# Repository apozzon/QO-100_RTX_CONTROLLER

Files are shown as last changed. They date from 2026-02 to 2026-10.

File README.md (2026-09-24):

# QO-100_RTX_CONTROLLER
QO-100 RTX CONTROLLER
ESP32 CONTROLLER for QO100
 	 	 	 	 	 	 	 	 	 	 	 	 	 	 	 	 
 	QO-100 RTX		IP		SSID		PASSW	 
 	Controller		192.168.0.214		SKYAP2		************	 
 																 
 	ON/OFF		DATV		GPSDO		FAN		…		…		…		…	 

 	V in		V pow		A pow		mW in		W out		W ref		SWR		T air-pow	 
 	13.8		27.5		1.5		10		7,5		0,6		1,788789		19-33	 

DRAFT COPY - SOON IN ENGLISH

Misure
Parametro	Max	PIN	Note
V ingresso	13.8 V	1	Partitore 1:10
V potenza	30V	2	Partitore 1:10
A potenza	10A	3	Parallelo a R 0,1 ohm da 5 W (10A = 1V)
W power in 	5V	4	
W power out	5V	5	
W reflected	5V	6	
C temperatura	60C	11	Apposito modulo digitale

Controlli
Parametro	Stato	PIN	Note
On / Off	0-1	7	Accende e spegne SDR – Arduino sempre on low
DATV	0-1	8	Commuta 12V-18V su Bias-T
Heat	0-1	9	Accende resistenza riscaldamento clima freddo

INSTALLAZIONE IDE E SETTAGGIO BOARD
Setup Steps for Arduino IDE
1.	Open Arduino IDE and go to File > Preferences.
2.	Add Board Manager URL: Paste the following into the "Additional Boards Manager URLs" field:
https://raw.githubusercontent.com/espressif/arduino-esp32/gh-pages/package_esp32_index.json.
3.	Install Boards: Go to Tools > Board > Boards Manager, search for "esp32" and install the latest version by Espressif Systems.
 
NB: se non carica support mettere queste due istruzioni in C:\Users\Andrea.DESKTOP-IK5K4JJ\.arduinoIDE\ arduino-cli.yaml
network:
  connection_timeout: 300s

4.	Select Board: Select Tools > Board > ESP32 Arduino > ESP32S3 Dev Module.
5.	Configure Tools Menu (Crucial for N16R8):
1.	USB CDC On Boot: "Enabled" (Allows Serial.print via USB).
2.	Flash Size: "16MB (128Mb)".
3.	Flash Mode: "QIO 80MHz" or "QOIO 80MHz".
4.	Partition Scheme: "16M Flash (3M APP/9.9M FATFS)" or similar large partition.
5.	PSRAM: "OPI PSRAM".
6.	Upload: Connect the board, select the correct Port, and upload a test sketch. 

ARDUINO
Additional board manager URL: https://espressif.github.io/arduino-esp32/package_esp32_index.json
Board scelta : ESP32S3 Dev Module

Librerie
https://github.com/ESP32Async/AsyncTCP
https://github.com/ESP32Async/ESPAsyncWebServer
DHT kxn

Java aggiunta libreria Google json
tasto destro su Progetto – Build Path -Add External Archives) – Scegliere file scaricato (es.  gson-2.3.1.jar)

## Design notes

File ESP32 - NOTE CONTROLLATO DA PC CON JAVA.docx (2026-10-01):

# ESP32 CONTROLLER PER QO100

https://github.com/apozzon/QO-100_RTX_CONTROLLER

| QO-100 RTX | | | | IP | | | | SSID | | | | PASSW
| Controller | | | | 192.168.0.214 | | | | SKYAP2 | | | | ************
| ON/OFF | | DATV | | GPSDO | | … | | … | | … | | … | | …
| V in | | V pow | | A pow | | mW in | | W out | | W ref | | SWR | | T air-pow
| 13.8 | | 27.5 | | 1.5 | | 10 | | 7,5 | | 0,6 | | 1,78 | | 19-33

## Misure

Parametro | Max | PIN | Note
V ingresso | 13.8 V | 1 | Partitore 1:10
V potenza | 30V | 2 | Partitore 1:10
A potenza | 5A | 3 | ASC712-5A
W power in | 5V | 4
W power out | 5V | 5
W reflected | 5V | 6
C temperatura aria | 60C | 11 | DHT22
C P.A. | 60C | 10 | DB18S20

## Controlli

Parametro | Stato | PIN | Note
On / Off | 0-1 | 7 | Accende e spegne SDR – Arduino sempre on low
DATV | 0-1 | 8 | Commuta 12V-18V su Bias-T
GPSDO | 0-1 | 9 | Accende GPSDO

## ARDUINO - INSTALLAZIONE IDE E SETTAGGIO BOARD

Setup Steps for Arduino IDE

NB: se non carica support mettere queste due istruzioni in C:\Users\Andrea.DESKTOP-IK5K4JJ\.arduinoIDE\ arduino-cli.yaml

network:

connection_timeout: 300s

1. Open Arduino IDE and go to File > Preferences.
2. Add Board Manager URL: Paste the following into the "Additional Boards Manager URLs" field: https://raw.githubusercontent.com/espressif/arduino-esp32/gh-pages/package_esp32_index.json
3. https://github.com/ESP32Async/ESPAsyncWebServer
4. Install Boards: Go to Tools > Board > Boards Manager, search for "esp32" and install the latest version by Espressif Systems.

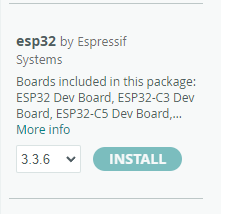
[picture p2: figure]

5. Select Board: Select Tools > Board > ESP32 Arduino > ESP32S3 Dev Module.
6. Configure Tools Menu (Crucial for N16R8):
  - USB CDC On Boot: "Enabled" (Allows Serial.print via USB).
  - Flash Size: "16MB (128Mb)".
  - Flash Mode: "QIO 80MHz" or "QOIO 80MHz".
  - Partition Scheme: "16M Flash (3M APP/9.9M FATFS)" or similar large partition.
  - PSRAM: "OPI PSRAM".
7. Upload: Connect the board, select the correct Port, and upload a test sketch.

## Installazione librerie

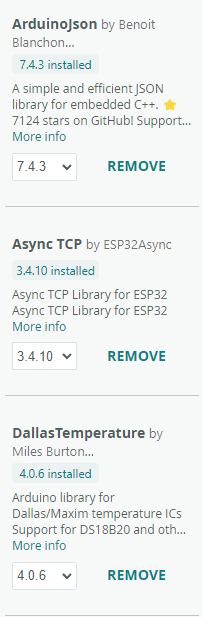
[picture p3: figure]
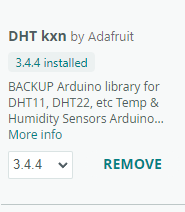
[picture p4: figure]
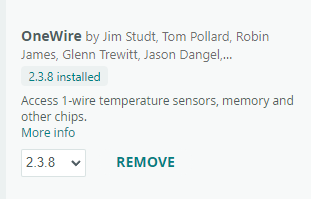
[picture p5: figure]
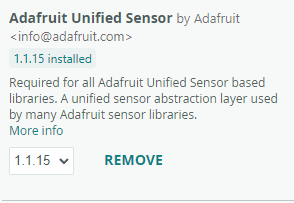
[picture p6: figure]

Vengono salvate nella directory di progetto

C:\Users\Andrea.DESKTOP-IK5K4JJ\OneDrive\RADIO\Autocostruzione\OSCAR-100\$ Programmazione\Arduino_ESP32\libraries

Si possono copiare nella nuova installazione chiudere e riaprire IDE che si caricano da sole.

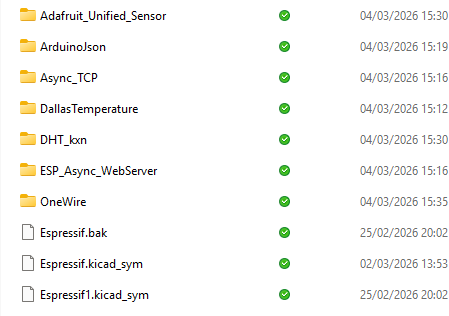
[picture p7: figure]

# JAVA aggiunta libreria Google json

tasto destro su Progetto – Build Path -Add External Archives) – Scegliere file scaricato (es. gson-2.3.1.jar)

Compilazione

File -> Export

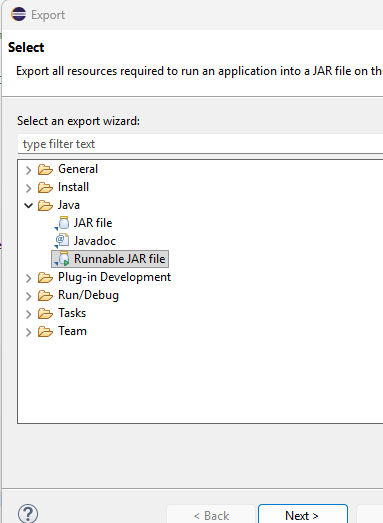
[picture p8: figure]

Launch4j

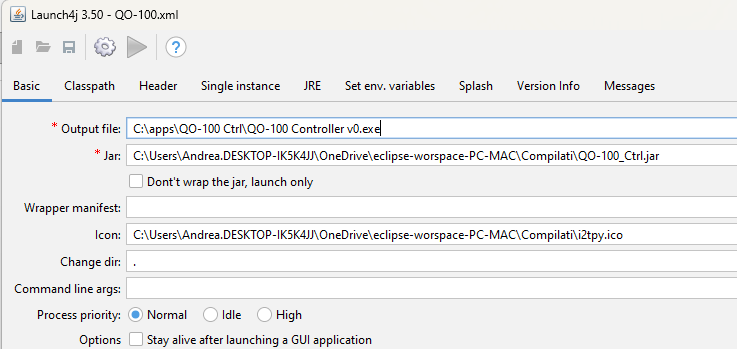
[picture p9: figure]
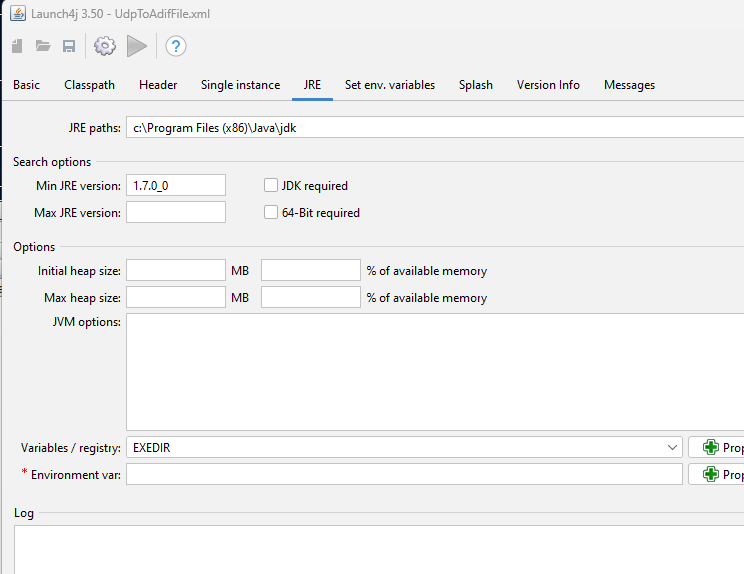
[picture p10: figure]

PER USO PROGRAMMA SERVE:

- JDK INSTALLATA IN "C:\Program Files (x86)\Java\jdk"

## CONTROL BOARD

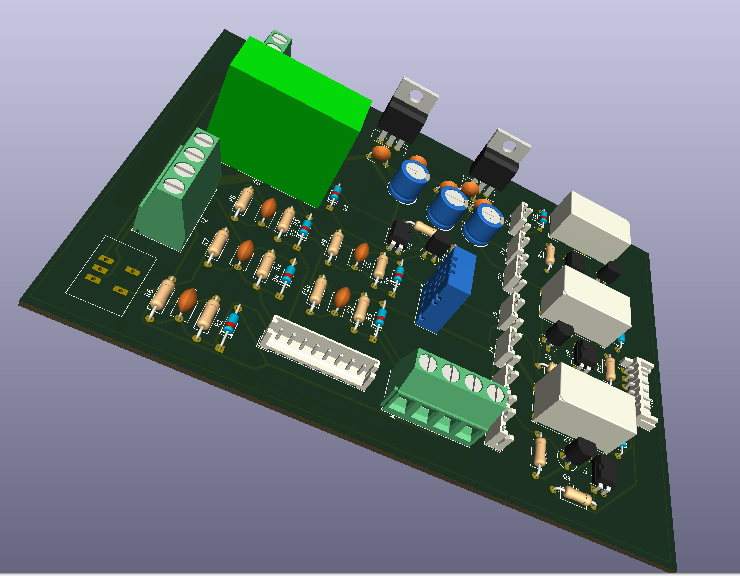
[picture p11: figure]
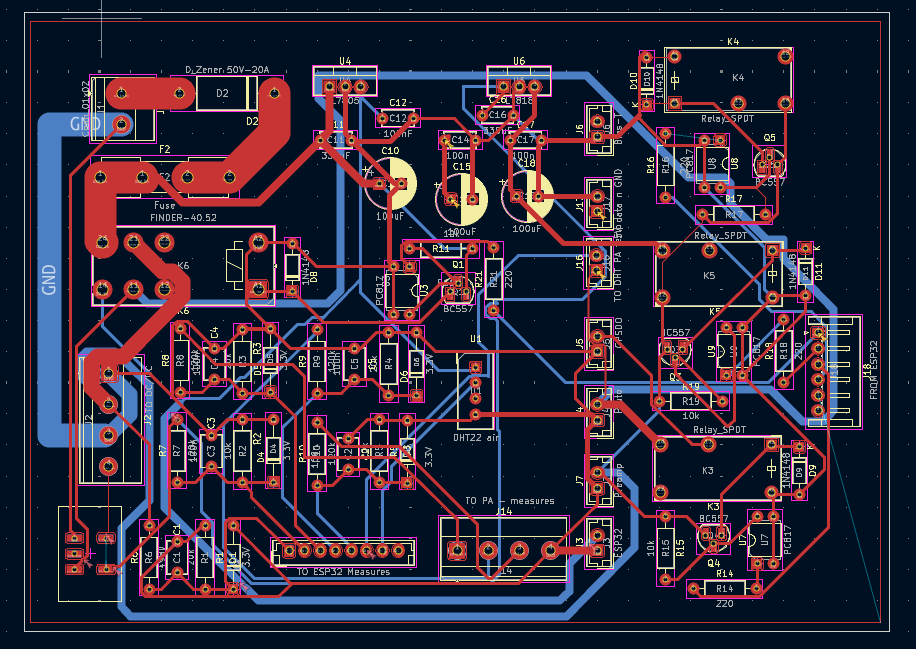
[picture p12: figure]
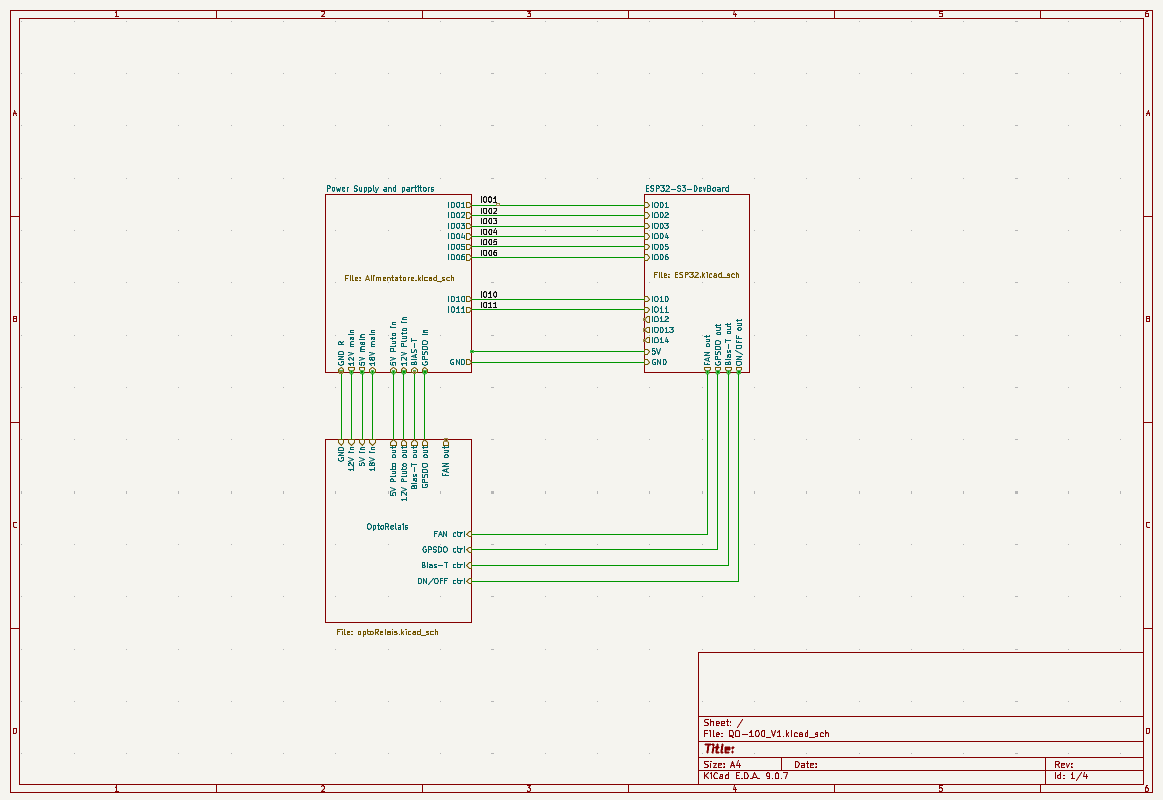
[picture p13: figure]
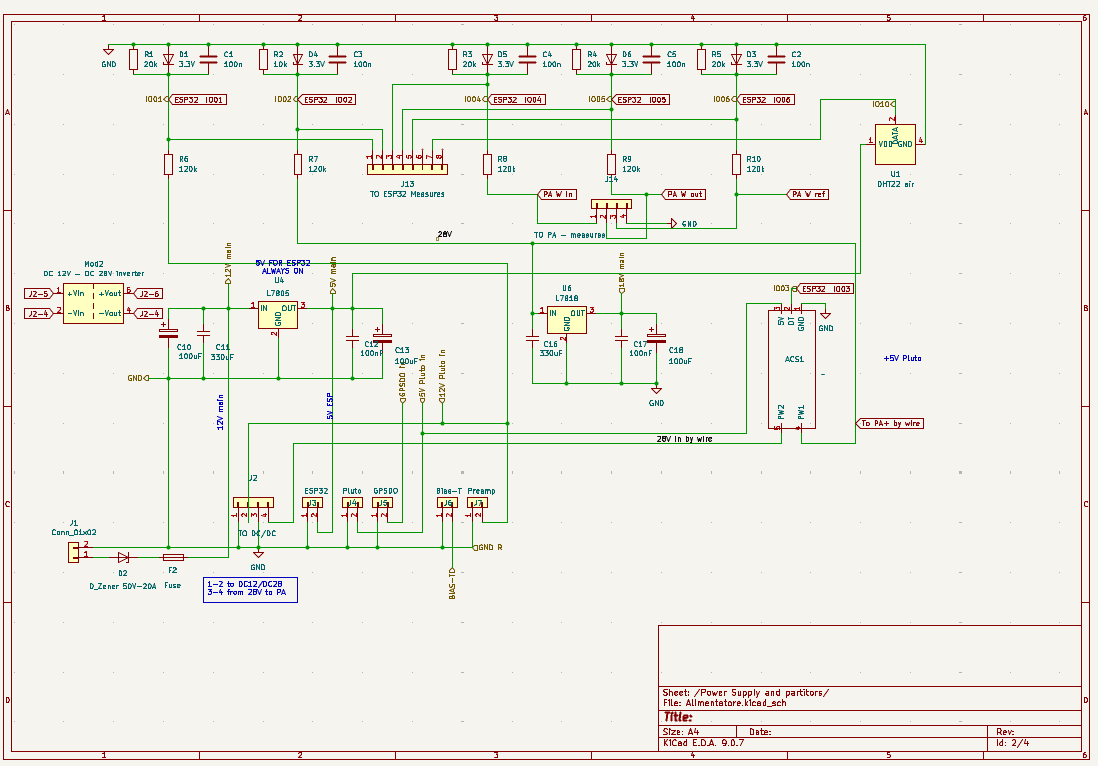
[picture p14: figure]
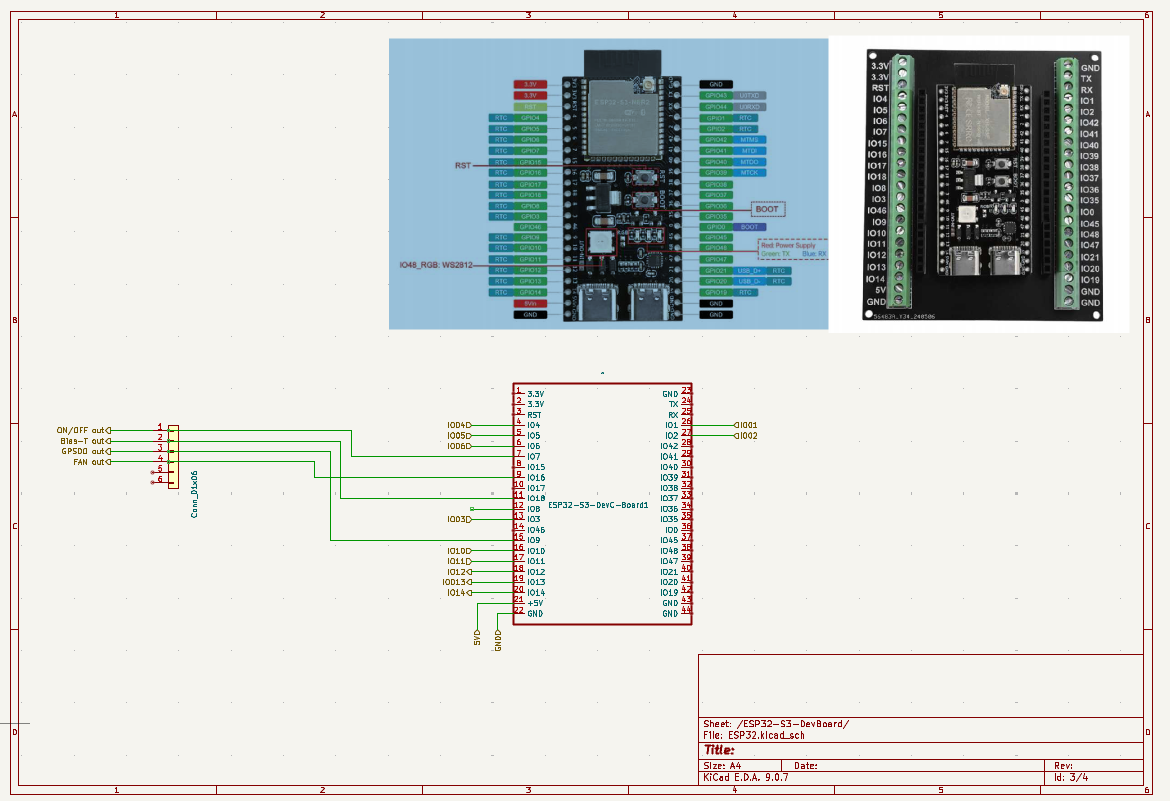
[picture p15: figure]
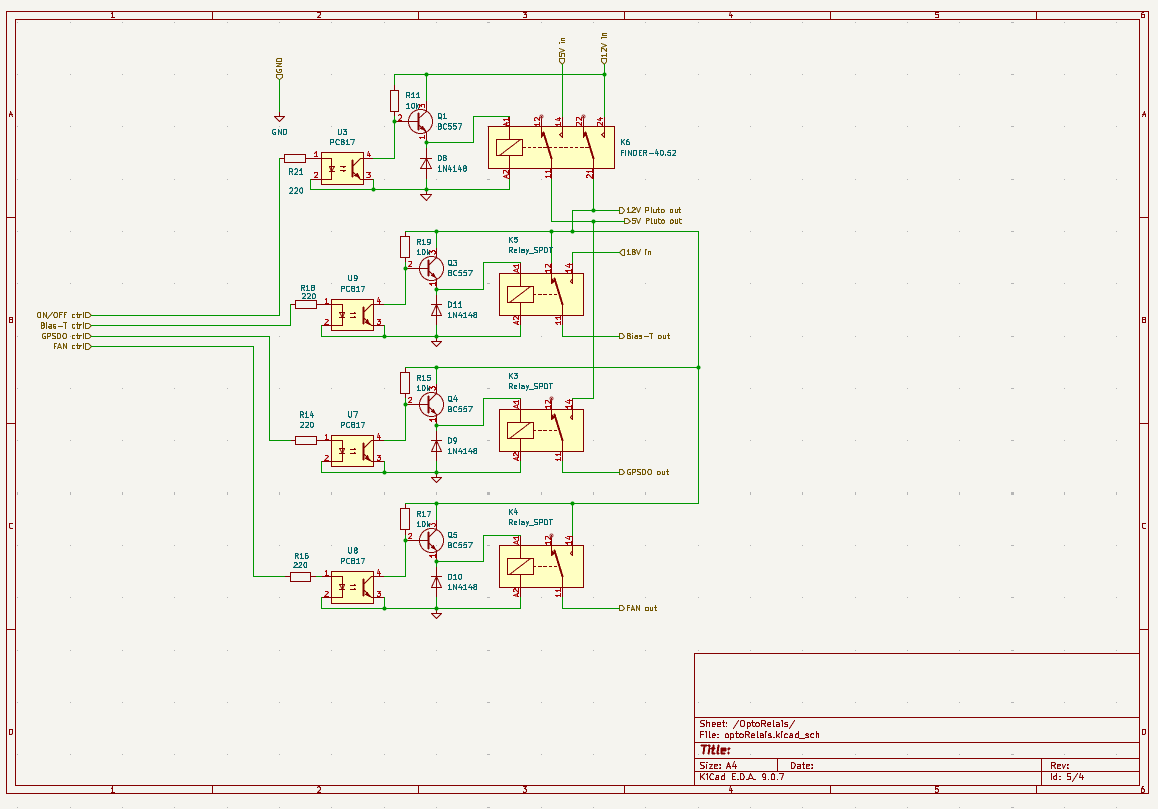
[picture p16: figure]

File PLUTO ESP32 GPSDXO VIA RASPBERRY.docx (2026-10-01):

# PLUTO, ESP32 and GPSDXO VIA RASPBERRY

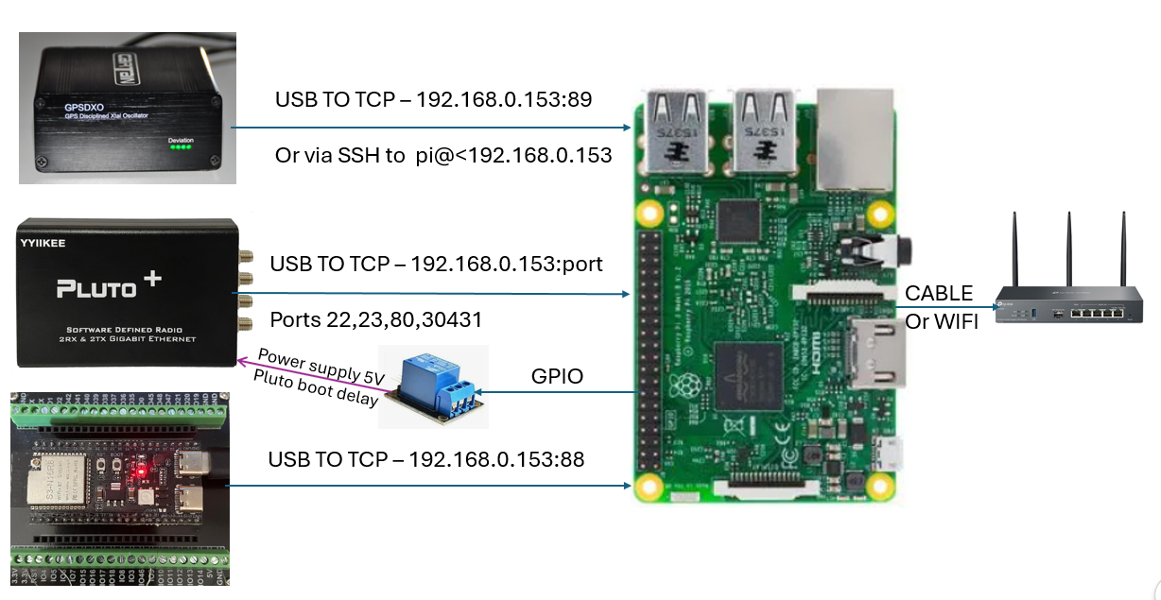
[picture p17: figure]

## Preparation of the SD Card for the Pi and basic configuration

1) Prepare an SD card for Raspberry Pi with OS 32bits Light using the Raspberry Imager or other system and connect the Pi to the PC via USB
2) Connect to the Pi via SSH (for example using Putty COMxx on port 22)
3) Login with username and password you defined in the Raspberry Imager
4) Install iptables

sudo apt install iptables

sudo apt install iptables-persistent -y

sudo apt install tcpdump -y (only for tests if something goes wrong)

5) Verify the connection of the Pluto using the command “ip a”

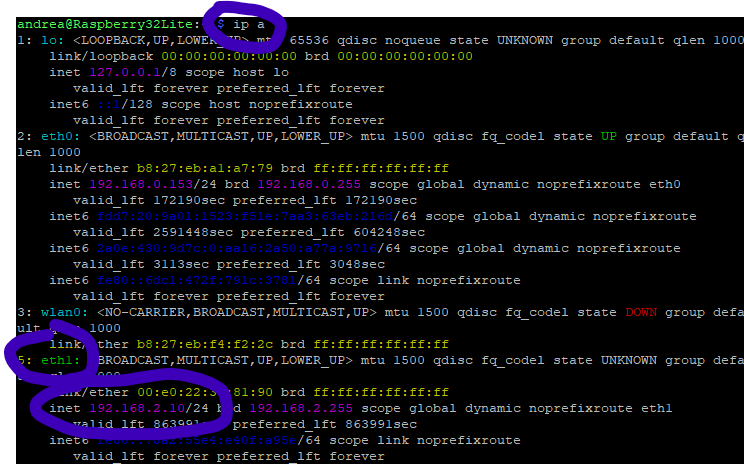
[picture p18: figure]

6) To connect to the Pluto from the PC we have to forward what arriving on the ethernet port (for me 192.168.0.151) of the Pi to the USB port (eth1). To avoid connection conflicts, the port to connect to Pluto cannot be 22 used by the Pi but a different number (for me 23). WEW need to re-route cdata from eth0 (lan) to eth1 (USB. Unfortunately, eth0 and eth1 can swap depending on the start sequence so, before create the port forwarding, it is better to name the device Pluto with a specific name through an UDEV rule (in my case I called it pluto-usb). The rule should work with any Adalm Pluto or Plus Plus because it is recognized by vendor and product ID.

## Mapping a logic channel to Pluto

It is a native ethernet channel between network (ethrnet or wifi) and the standrad IP port of Pluto (192.168.2.1) visible through a virtual interface (ie eth0, usb0…). The software (ie SDR Console od Putty on a PC) can access though standard ports (22, 23), 80, 30431 etc.).

## Port Mapping for Raspberry Pi3+ with OS 32 bits

Note: nano editor can be closed with ctrl+X and the file saved following the instructions on screen.

Create a configuration file for UDEV

sudo nano /etc/udev/rules.d/99-pluto-net.rules

insert the following line

SUBSYSTEM=="net", ACTION=="add", ATTRS{idVendor}=="0456", ATTRS{idProduct}=="b673", NAME="pluto-usb"

As alternate write in the specific mac address of your Pluto (you can read it with the command “ip link show dev eth0 or eth1). This solution is much stronger but you cannot change pluto without changing the setup.

SUBSYSTEM=="net", ACTION=="add", ATTR{address}=="00:e0:22:3c:81:90", NAME="pluto-usb"

check that it works

ip a

if not restart the Pi.

## Port Mapping for Raspberry Pi3+ with OS 64 bits (untested!!!)

Create a configuration file

sudo nano /etc/NetworkManager/conf.d/10-pluto-usb.conf

insert the following lines

[device-pluto-usb]

match-device=match-property:ID_VENDOR_ID==0456,match-property:ID_MODEL_ID==b673

set-name=pluto-usb

Disconnect and reconnect UDEV

sudo udevadm control --reload-rules sudo udevadm trigger --attr-match=subsystem=net

Restart the NetworkManager

sudo systemctl restart NetworkManager

check that it works

ip a

if not restart the Pi.

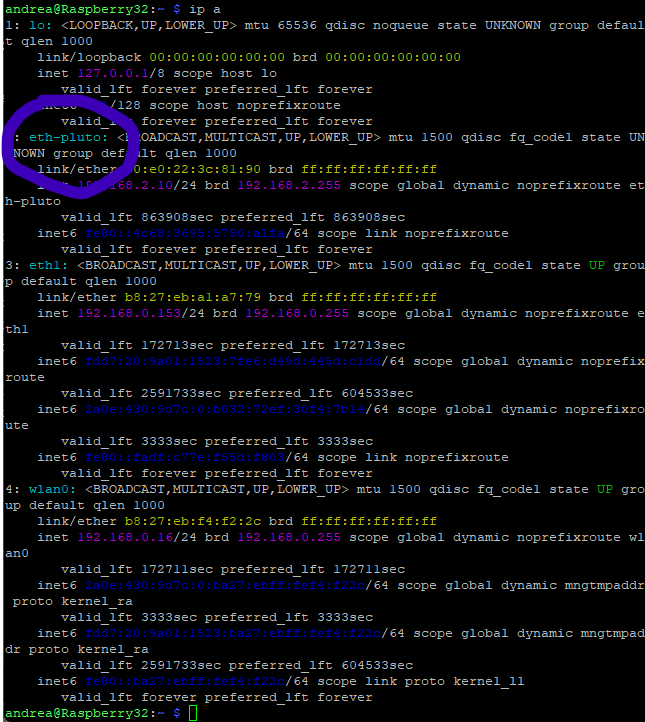
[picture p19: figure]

(eth-pluto now pluto-usb to avoid naming convention problems)

## Setup the Port forwarding

Create a configuration file read at the startup

sudo nano /etc/sysctl.d/99-ip-forward.conf

with this line

net.ipv4.ip_forward=1

Clean the NAT table

sudo iptables -t nat -F

# Port Forwarding (Porta 23 SSH, Porta 80 Web, Porta 30431 SDR IIO)

sudo iptables -t nat -A PREROUTING -p tcp --dport 23 -j DNAT --to-destination 192.168.2.1:22

sudo iptables -t nat -A PREROUTING -p tcp --dport 80 -j DNAT --to-destination 192.168.2.1:80

sudo iptables -t nat -A PREROUTING -p tcp --dport 30431 -j DNAT --to-destination 192.168.2.1:30431

# Masquerade verso l'interfaccia fissa del Pluto

sudo iptables -t nat -A POSTROUTING -o pluto-usb -j MASQUERADE

Rewrite the routing table

sudo iptables-save | sudo tee /etc/iptables/rules.v4

That’s it, at restart you can test the connection with the Pluto

1. via SSH with the same IP address of the Pi but using port 23
2. via a web browser using the same ip address on the standard port 80
3. with SDR Console using the standard port 30431
4. any other system…

Other ports to other devices can be forwarded using the same system.

Testing active routing

sudo iptables -t nat -v -L -n --line-numbers

# Next step: connect also ESP32 via USB

## Mapping a logic channel to ESP 32

We need a separate channel to ESP32 that does not have an IP defined to reach to like Pluto has.

The “socat” command creates a TCP port on the Raspberry and maps it to the serial port of ESP32 (es. /dev/ttyUSB0).

Procedure:

Find the correct port of the ESP32

Unplug the ESP32 and plug it again

ls /dev/ttyUSB* /dev/ttyACM*

Find the hardware details of the connected ESP32

lsusb

Giving back something like

Bus 001 Device 004: ID 0403:6001 Future Technology Devices International, Ltd FT232 Serial (UART) IC

idVendor = 0402

idProduct = 6001

find the proper name

udevadm info -a -n /dev/ttyUSB0 | grep '{serial}'

Add it to the UDEV definition file already in place for Pluto id

sudo nano /etc/udev/rules.d/99-usb-serial.rules

add this line (symlink it’s a symbolic permanett link)

SUBSYSTEM=="tty", ATTRS{idVendor}=="0403", ATTRS{idProduct}=="6001", SYMLINK+="myESP32"

SUBSYSTEM=="tty", ATTRS{idVendor}=="0403", ATTRS{idProduct}=="7523", SYMLINK+="myGPSDXO"

Or if you have more than one ESP32

SUBSYSTEM=="tty", ATTRS{idVendor}=="0403", ATTRS{idProduct}=="6001", ATTRS{serial}=="A9008xFF", SYMLINK+="myESP32”

Ctrl+X to save

Restart UDEV or restart the Raspberry to make the mod’s active.

sudo udevadm control --reload-rules

sudo udevadm trigger

## Expose the ESP32 via TCP

To make ESP32 reachable from any PC and not only the local host (127.0.0.1), socan must be modified to listen to all interfaces using the ip 0.0.0.0

socat TCP-LISTEN:88,fork,reuseaddr,bind=0.0.0.0 FILE:/dev/ttyUSB0,b115200,raw,echo=0

or

socat TCP-LISTEN:88,fork,reuseaddr,bind=0.0.0.0 FILE:/dev/myESP32,b115200,raw,echo=0

From this moment all data sent to 192.168.0.153:88 will go back and forth the ESP32.

To make it valid after shutdown and restart it must be included in a system service created with systemd:

sudo nano /etc/systemd/system/esp32-bridge.service

lines to input

[Unit]

Description=Socat Serial TCP Bridge per ESP32

After=network.target

[Service]

Type=simple

ExecStart=/usr/bin/socat TCP-LISTEN:88,fork,reuseaddr,bind=0.0.0.0 FILE:/dev/myESP32,b115200,raw,echo=0

Restart=always

RestartSec=5

[Install]

WantedBy=multi-user.target

Not it has to be read and started and authorized for automatic execution

Reload configuration of systemd

sudo systemctl daemon-reload

Authorize the automatic execution at startup

sudo systemctl enable esp32-bridge.service

Start the service immediatly

sudo systemctl start esp32-bridge.service

Test restart of the Raspberry and pray.

# Next step: connect also GPSDXO via U

## Mapping a logic channel to GPSDXO

Explanation same as per ESP32!!! Since the required connection is only SSH (no TCP) there is a shorter way that does not require other that define the UDEV device

Procedure (just name change):

Find the correct port of the GPSDXO

Unplug the GPSDXO and plug it again

ls /dev/ttyUSB* /dev/ttyACM*

Find the hardware details of the connected GPSDXO

lsusb

Giving back something like

Bus 001 Device 004: ID 0403:6001 Future Technology Devices International, Ltd FT232 Serial (UART) IC

idVendor = 0402

idProduct = 6001

find the proper name

udevadm info -a -n /dev/ttyUSB0 | grep '{serial}'

Add it to the UDEV definition file already in place for Pluto id

sudo nano /etc/udev/rules.d/99-usb-serial.rules

add this line (symlink it’s a symbolic permanett link)

SUBSYSTEM=="tty", ATTRS{idVendor}=="0403", ATTRS{idProduct}=="7523", SYMLINK+="myGPSDXO"

Or if you have more than one GPSDXO

SUBSYSTEM=="tty", ATTRS{idVendor}=="0403", ATTRS{idProduct}=="6001", ATTRS{serial}=="B9008xFF", SYMLINK+="myGPSDXO”

Ctrl+X to save

Restart UDEV or restart the Raspberry to make the mod’s active.

sudo udevadm control --reload-rules

sudo udevadm trigger

At this point to connect the GPSDXO from the PC you can just type in CMD

ssh -t pi@<IP_DEL_RASPBERRY> "minicom -D /dev/myGPSDXO -b 115200"

## If you need GPSDXO via TCP

To make GPSDXO reachable from any PC and not only the local host (127.0.0.1), must be modified to listen to all interfaces using the ip 0.0.0.0

socat TCP-LISTEN:89,fork,reuseaddr,bind=0.0.0.0 FILE:/dev/myGPSDXO,b115200,raw,echo=0

From this moment all data sent to 192.168.0.153:88 will go back and forth the GPSDXO.

To make it valid after shutdown and restart it must be included in a system service created with systemd:

sudo nano /etc/systemd/system/gpsdxo-bridge.service

lines to input

[Unit]

Description=Socat Serial TCP Bridge per GPSDXO

After=network.target

[Service]

Type=simple

ExecStart=/usr/bin/socat TCP-LISTEN:89,fork,reuseaddr,bind=0.0.0.0 FILE:/dev/myGPSDXO,b115200,raw,echo=0

Restart=always

RestartSec=5

[Install]

WantedBy=multi-user.target

Not it has to be read and started and authorized for automatic execution

Reload configuration of systemd

sudo systemctl daemon-reload

Authorize the automatic execution at startup

sudo systemctl enable gpsdxo-bridge.service

Start the service immediatly

sudo systemctl start gpsdxo-bridge.service

Test restart of the Raspberry and pray.

⚠️ Warning 1⚡

Be sure that the power supplied to Pluto, ESP and GPSDXO will not go all though the Raspberry because it can handle max 1.25A in total (summing up all USB connected consumptions). Pluto cannot be powed though Raspberry!!! It works receiving but get stuck if you try to transmit.

You might want to add a USB Hub to connect your devices.

⚠️ Warning 2

Pluto requires that the GPSDXO signal (40 MHz) is available when turned on instead it gets stuck. Normally GPSDXO generates the RF signal when starts but it may take too long for Pluto. To avoid troubles, it is better to delay the Pluto startup after that the Pi and GPSDXO are on.

If you put a timer, remember to cut the red wire of the USB cable from the Pi to the Pluto to avoid Pluto getting power directly from the Pi.

That is not mandatory, but it solves unpredictable problems when you turn the system on.

SOLUTION

1) Cut the red wire of the USB connection to the Pluto DATA and use a 5V photocoupled relays module connected to the Pi’s GPIO:

VCC Pin 4 or 2

GND Pin 6

IN Signal Pin 11 (GPIO 17)

Connect COM (common) to 5V supply and NO + GND to Pluto POWER USB input.

2) Create a Python timer to control the delay the relays when the Pi starts.

nano /home/pi/pluto_start.py

add lines

import time

from gpiozero import OutputDevice

# Wait 1 minute from beginning of the script launched in the startup sequence

time.sleep(60)

# GPIO 17 (Pin 11) configuration (active_high=false in case of inverted logic)

rele = OutputDevice(17, active_high=True, initial_value=False)

# Turn on the realay (hence Pluto)

rele.on()

3) Create the system service

sudo nano /etc/systemd/system/pluto-timer.service

add lines

[Unit]

Description=Delayed Pluto boot

After=multi-user.target

[Service]

Type=simple

ExecStart=/usr/bin/python3 /home/pi/pluto_start.py

Restart=on-failure

[Install]

WantedBy=multi-user.target

4) Service habilitation to be executed at each boot

sudo systemctl daemon-reload

sudo systemctl enable pluto-timer.service

GL and 73 by I2TPY

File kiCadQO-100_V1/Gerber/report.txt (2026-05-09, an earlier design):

Plotted to 'C:\Users\Andrea.DESKTOP-IK5K4JJ\OneDrive\RADIO\Autocostruzione\OSCAR-100\kiCad QO-100_V1\QO-100_V1\QO-100_V1-F_Cu.gbr'.
Plotted to 'C:\Users\Andrea.DESKTOP-IK5K4JJ\OneDrive\RADIO\Autocostruzione\OSCAR-100\kiCad QO-100_V1\QO-100_V1\QO-100_V1-B_Cu.gbr'.
Plotted to 'C:\Users\Andrea.DESKTOP-IK5K4JJ\OneDrive\RADIO\Autocostruzione\OSCAR-100\kiCad QO-100_V1\QO-100_V1\QO-100_V1-F_Paste.gbr'.
Plotted to 'C:\Users\Andrea.DESKTOP-IK5K4JJ\OneDrive\RADIO\Autocostruzione\OSCAR-100\kiCad QO-100_V1\QO-100_V1\QO-100_V1-B_Paste.gbr'.
Plotted to 'C:\Users\Andrea.DESKTOP-IK5K4JJ\OneDrive\RADIO\Autocostruzione\OSCAR-100\kiCad QO-100_V1\QO-100_V1\QO-100_V1-F_Silkscreen.gbr'.
Plotted to 'C:\Users\Andrea.DESKTOP-IK5K4JJ\OneDrive\RADIO\Autocostruzione\OSCAR-100\kiCad QO-100_V1\QO-100_V1\QO-100_V1-B_Silkscreen.gbr'.
Plotted to 'C:\Users\Andrea.DESKTOP-IK5K4JJ\OneDrive\RADIO\Autocostruzione\OSCAR-100\kiCad QO-100_V1\QO-100_V1\QO-100_V1-F_Mask.gbr'.
Plotted to 'C:\Users\Andrea.DESKTOP-IK5K4JJ\OneDrive\RADIO\Autocostruzione\OSCAR-100\kiCad QO-100_V1\QO-100_V1\QO-100_V1-B_Mask.gbr'.
Plotted to 'C:\Users\Andrea.DESKTOP-IK5K4JJ\OneDrive\RADIO\Autocostruzione\OSCAR-100\kiCad QO-100_V1\QO-100_V1\QO-100_V1-Edge_Cuts.gbr'.
Created Gerber job file 'C:\Users\Andrea.DESKTOP-IK5K4JJ\OneDrive\RADIO\Autocostruzione\OSCAR-100\kiCad QO-100_V1\QO-100_V1\QO-100_V1-job.gbrjob'.
Info: Done.
Info: Done.

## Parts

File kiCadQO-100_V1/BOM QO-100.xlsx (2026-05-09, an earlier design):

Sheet: QO-100
Id | Designator | Footprint | Quantity | Designation | Supplier and ref
4 | ACS1 | ACS712 | 1 | ~
21 | U1 | Aosong_DHT11_5.5x12.0_P2.54mm | 1 | DHT22 air
7 | C14,C12,C17 | C_Disc_D5.0mm_W2.5mm_P5.00mm | 3 | 100nF
23 | C16,C11 | C_Disc_D5.0mm_W2.5mm_P5.00mm | 2 | 330uF
18 | C4,C5,C1,C2,C3 | C_Disc_D5.1mm_W3.2mm_P5.00mm | 5 | 100n
11 | C10,C15,C13,C18 | CP_Radial_D8.0mm_P3.50mm | 4 | 100uF
27 | D2 | D_DO-27_P15.24mm_Horizontal | 1 | D_Zener 50V-20A
12 | D3,D6,D1,D4,D5 | D_DO-35_SOD27_P10.16mm_Horizontal | 5 | 3.3V
2 | D9,D11,D8,D10 | D_DO-35_SOD27_P7.62mm_Horizontal | 4 | 1N4148
6 | U7,U8,U3,U9 | DIP-4_W7.62mm Optoisolatori | 4 | PC817
14 | F2 | Fuseholder_Clip-5x20mm_Eaton_1A5601-01_Inline_P20.80x6.76mm_D1.70mm_Horizontal | 1 | Fuse
5 | J16 | JST_EH_B2B-EH-A_1x02_P2.50mm_Vertical | 1 | a-DS18S20
13 | J6 | JST_EH_B2B-EH-A_1x02_P2.50mm_Vertical | 1 | Bias-T
19 | J5 | JST_EH_B2B-EH-A_1x02_P2.50mm_Vertical | 1 | GPSDO
25 | J4 | JST_EH_B2B-EH-A_1x02_P2.50mm_Vertical | 1 | Pluto
26 | J7 | JST_EH_B2B-EH-A_1x02_P2.50mm_Vertical | 1 | Preamp
29 | J3 | JST_EH_B2B-EH-A_1x02_P2.50mm_Vertical | 1 | ESP32
31 | J17 | JST_EH_B2B-EH-A_1x02_P2.50mm_Vertical | 1 | b-DS18S20
32 | J13 | JST_EH_B8B-EH-A_1x08_P2.50mm_Vertical | 1 | TO ESP32 Measures
24 | J18 | JST_EH_S6B-EH_1x06_P2.50mm_Horizontal | 1 | FROM ESP32
9 | R19,R2,R15,R11,R17 | R_Axial_DIN0207_L6.3mm_D2.5mm_P10.16mm_Horizontal | 5 | 10k
10 | R8,R10,R9,R6,R7 | R_Axial_DIN0207_L6.3mm_D2.5mm_P10.16mm_Horizontal | 5 | 120k
16 | R3,R5,R1,R4 | R_Axial_DIN0207_L6.3mm_D2.5mm_P10.16mm_Horizontal | 4 | 20k
20 | R14,R16,R18,R21 | R_Axial_DIN0207_L6.3mm_D2.5mm_P10.16mm_Horizontal | 4 | 220
8 | K6 | Relay_DPDT_Finder_40.52 | 1 | FINDER-40.52
3 | K5,K3,K4 | Relay_SPDT_Finder_32.21-x000 | 3 | Relay_SPDT
15 | J1 | TerminalBlock_Phoenix_MKDS-1,5-2_1x02_P5.00mm_Horizontal | 1 | Conn_01x02
17 | J14 | TerminalBlock_Phoenix_MKDS-1,5-4_1x04_P5.00mm_Horizontal | 1 | TO PA - measures
28 | J2 | TerminalBlock_Phoenix_MKDS-1,5-4_1x04_P5.00mm_Horizontal | 1 | TO DC/DC
22 | U4 | TO-220-3_Vertical | 1 | L7805
30 | U6 | TO-220-3_Vertical | 1 | L7818
1 | Q1,Q4,Q3,Q5 | TO-92_HandSolder | 4 | BC557

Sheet: Sheet1
Partitori
Vin | 5 | 14 | 30
Rin | 100 | 100 | 100
Rgnd | 100 | 56 | 10
Vout | 2.5 | 5.025641026 | 2.727272727
Conversion | 2 | 2.785714286 | 11 | da mettere a programma
Misura corrente
A | 5
Shunt ohm | 0.1
V r | 0.5

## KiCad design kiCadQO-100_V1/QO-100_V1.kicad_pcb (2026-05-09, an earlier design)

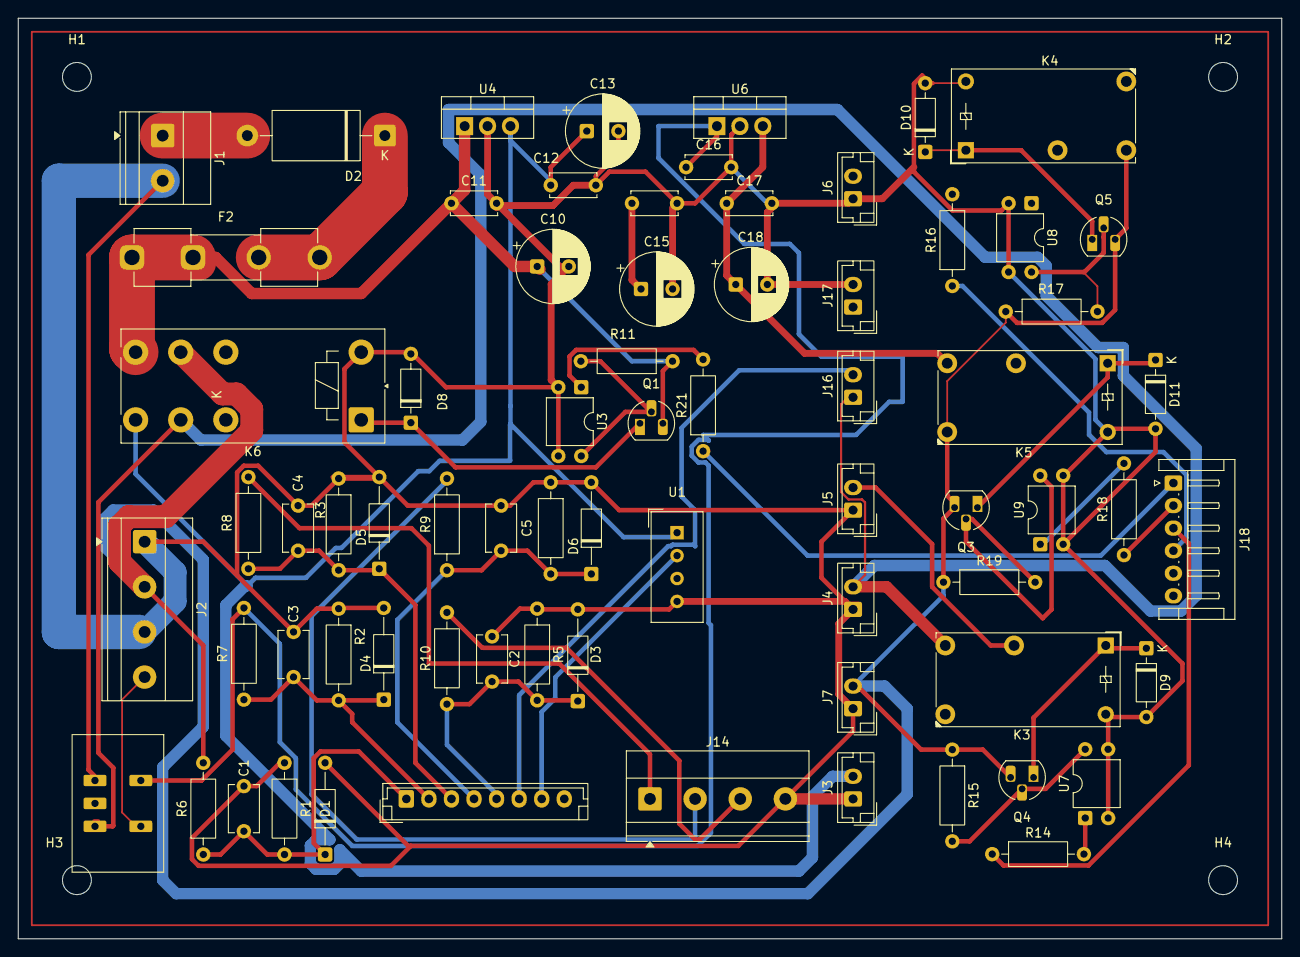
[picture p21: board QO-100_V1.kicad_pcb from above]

Board: 2 copper layers, 140.0 x 102.0 mm, 75 parts (0 on the bottom side), 38 nets.

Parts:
ACS1: ACS712
C1, C2, C3, C4, C5: 100n; C_Disc_D5.1mm_W3.2mm_P5.00mm
C10, C13, C15, C18: 100uF; CP_Radial_D8.0mm_P3.50mm
C11, C16: 330uF; C_Disc_D5.0mm_W2.5mm_P5.00mm
C12, C14, C17: 100nF; C_Disc_D5.0mm_W2.5mm_P5.00mm
D1, D3, D4, D5, D6: 3.3V; D_DO-35_SOD27_P10.16mm_Horizontal
D2: D_Zener 50V-20A; D_DO-27_P15.24mm_Horizontal
D8, D9, D10, D11: 1N4148; D_DO-35_SOD27_P7.62mm_Horizontal
F2: Fuse; Fuseholder_Clip-5x20mm_Eaton_1A5601-01_Inline_P20.80x6.76mm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
H1, H2, H3, H4: MountingHole; MountingHole_3.2mm_M3
J1: Conn_01x02; TerminalBlock_Phoenix_MKDS-1,5-2_1x02_P5.00mm_Horizontal
J2: TO DC/DC; TerminalBlock_Phoenix_MKDS-1,5-4_1x04_P5.00mm_Horizontal
J3: ESP32; JST_EH_B2B-EH-A_1x02_P2.50mm_Vertical
J4: Pluto; JST_EH_B2B-EH-A_1x02_P2.50mm_Vertical
J5: GPSDO; JST_EH_B2B-EH-A_1x02_P2.50mm_Vertical
J6: Bias-T; JST_EH_B2B-EH-A_1x02_P2.50mm_Vertical
J7: Preamp; JST_EH_B2B-EH-A_1x02_P2.50mm_Vertical
J13: TO ESP32 Measures; JST_EH_B8B-EH-A_1x08_P2.50mm_Vertical
J14: TO PA - measures; TerminalBlock_Phoenix_MKDS-1,5-4_1x04_P5.00mm_Horizontal
J16: a-DS18S20; JST_EH_B2B-EH-A_1x02_P2.50mm_Vertical
J17: b-DS18S20; JST_EH_B2B-EH-A_1x02_P2.50mm_Vertical
J18: FROM ESP32; JST_EH_S6B-EH_1x06_P2.50mm_Horizontal
K3, K4, K5: Relay_SPDT; Relay_SPDT_Finder_32.21-x000
K6: FINDER-40.52; Relay_DPDT_Finder_40.52
Q1, Q3, Q4, Q5: BC557; TO-92_HandSolder
R1, R3, R4, R5: 20k; R_Axial_DIN0207_L6.3mm_D2.5mm_P10.16mm_Horizontal
R2, R11, R15, R17, R19: 10k; R_Axial_DIN0207_L6.3mm_D2.5mm_P10.16mm_Horizontal
R6, R7, R8, R9, R10: 120k; R_Axial_DIN0207_L6.3mm_D2.5mm_P10.16mm_Horizontal
R14, R16, R18, R21: 220; R_Axial_DIN0207_L6.3mm_D2.5mm_P10.16mm_Horizontal
U1: DHT22 air; Aosong_DHT11_5.5x12.0_P2.54mm
U3, U7, U8, U9: PC817; DIP-4_W7.62mm
U4: L7805; TO-220-3_Vertical
U6: L7818; TO-220-3_Vertical

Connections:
/ESP32-S3-DevBoard/Bias-T out: J18.2, R18.1
/ESP32-S3-DevBoard/FAN out: J18.4, R16.1
/ESP32-S3-DevBoard/GPSDO out: J18.3, R14.1
/ESP32-S3-DevBoard/ON/OFF out: J18.1, R21.1
/IO10: J13.7, U1.2 (DATA)
/OptoRelais/5V Pluto out: ACS1.3 (5V), J4.2, J16.1, K3.14, K6.11
/OptoRelais/5V in: C12.1, C13.1, J3.2, K6.14, U1.1 (VDD), U4.3 (OUT)
/OptoRelais/12V Pluto out: J2.2, J7.2, K4.14, K5.12, K6.21, Q3.3 (C), Q4.3 (C), Q5.3 (C), R6.2, R15.1, R17.1, R19.1
/OptoRelais/12V in: C10.1, C11.1, F2.1, K6.24, Q1.3 (C), R11.1, U4.1 (IN)
/OptoRelais/18V in: C17.1, C18.1, K5.14, U6.3 (OUT)
/OptoRelais/GPSDO out: J5.2, K3.11
/Power Supply and partitors/5V Pluto: C14.1, C15.1
/Power Supply and partitors/28V in by wire: ACS1.5 (PW2), J2.4
GND: ACS1.1 (GND), C1.1, C2.1, C3.1, C4.1, C5.1, C10.2, C11.2, C12.2, C13.2, C14.2, C15.2, C16.2, C17.2, C18.2, D1.2 (A), D3.2 (A), D4.2 (A), D5.2 (A), D6.2 (A), D8.2 (A), D9.2 (A), D10.2 (A), D11.2 (A), J1.2, J2.1, J2.3, J3.1, J4.1, J5.1, J6.1, J7.1, J14.4, J17.2, K3.A2, K4.A2, K5.A2, K6.A2, R1.1, R2.1, R3.1, R4.1, R5.1, U1.4 (GND), U3.2, U3.3, U4.2 (GND), U6.2 (GND), U7.2, U7.3, U8.2, U8.3, U9.2, U9.3
unnamed: C1.2, D1.1 (K), J13.1, R1.2, R6.1
unnamed: D2.2 (A), J1.1
unnamed: D2.1 (K), F2.2
unnamed: C2.2, D3.1 (K), J13.5, R5.2, R10.1
unnamed: C3.2, D4.1 (K), J13.2, R2.2, R7.1
unnamed: C4.2, D5.1 (K), J13.3, R3.2, R8.1
unnamed: C5.2, D6.1 (K), J13.4, R4.2, R9.1
unnamed: D8.1 (K), K6.A1, Q1.1 (E)
unnamed: D9.1 (K), K3.A1, Q4.1 (E)
unnamed: D10.1 (K), K4.A1, Q5.1 (E)
unnamed: D11.1 (K), K5.A1, Q3.1 (E)
unnamed: J13.6, J16.2
unnamed: Q1.2 (B), R11.2, U3.4
unnamed: Q3.2 (B), R19.2, U9.4
unnamed: Q4.2 (B), R15.2, U7.4
unnamed: Q5.2 (B), R17.2, U8.4
unnamed: R14.2, U7.1
unnamed: R16.2, U8.1
unnamed: R18.2, U9.1
unnamed: R21.2, U3.1
PA W in: J14.1, R8.2
PA W out: J14.2, R9.2
PA W ref: J14.3, R10.2
To PA+ by wire: ACS1.4 (PW1), C16.1, R7.2, U6.1 (IN)

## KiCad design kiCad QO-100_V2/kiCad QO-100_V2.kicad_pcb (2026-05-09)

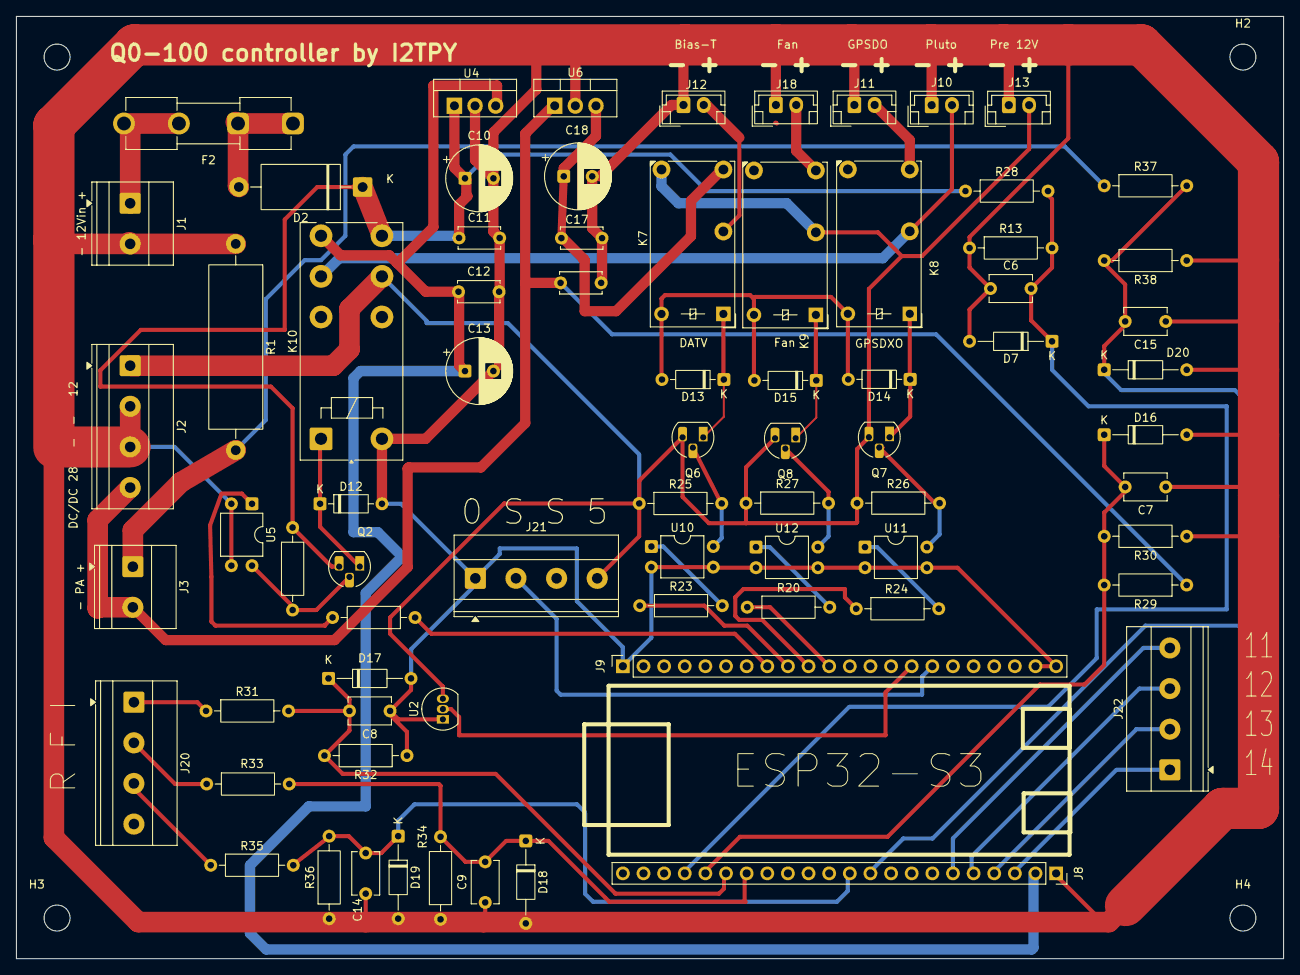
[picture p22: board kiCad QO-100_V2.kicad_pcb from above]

Board: 2 copper layers, 156.0 x 116.0 mm, 78 parts (0 on the bottom side), 44 nets.

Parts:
C6, C7, C8, C9, C14, C15: 100n; C_Disc_D5.1mm_W3.2mm_P5.00mm
C10, C13, C18: 100uF; CP_Radial_D8.0mm_P3.50mm
C11, C16: 330uF; C_Disc_D5.0mm_W2.5mm_P5.00mm
C12, C17: 100nF; C_Disc_D5.0mm_W2.5mm_P5.00mm
D2: D_Zener 50V-20A; D_DO-27_P15.24mm_Horizontal
D7, D16, D17, D18, D19, D20: 3.3V; D_DO-35_SOD27_P10.16mm_Horizontal
D12, D13, D14, D15: 1N4148; D_DO-35_SOD27_P7.62mm_Horizontal
F2: Fuse; Fuseholder_Clip-5x20mm_Eaton_1A5601-01_Inline_P20.80x6.76mm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
H1, H2, H3, H4: MountingHole; MountingHole_3.2mm_M3
J1: - 12Vin +; TerminalBlock_Phoenix_MKDS-1,5-2_1x02_P5.00mm_Horizontal
J2: DC/DC 28 - - 12; TerminalBlock_Phoenix_MKDS-1,5-4_1x04_P5.00mm_Horizontal
J3: - PA +; TerminalBlock_Phoenix_MKDS-1,5-2_1x02_P5.00mm_Horizontal
J8, J9: Conn_01x22_Socket; PinSocket_1x22_P2.54mm_Vertical
J10: Pluto; JST_EH_B2B-EH-A_1x02_P2.50mm_Vertical
J11: GPSDO; JST_EH_B2B-EH-A_1x02_P2.50mm_Vertical
J12: Bias-T; JST_EH_B2B-EH-A_1x02_P2.50mm_Vertical
J13: Pre 12V; JST_EH_B2B-EH-A_1x02_P2.50mm_Vertical
J18: Fan; JST_EH_B2B-EH-A_1x02_P2.50mm_Vertical
J20: TO PA - r f i; TerminalBlock_Phoenix_MKDS-1,5-4_1x04_P5.00mm_Horizontal
J21: DS18S20; TerminalBlock_Phoenix_MKDS-1,5-4_1x04_P5.00mm_Horizontal
J22: ExpansionA; TerminalBlock_Phoenix_MKDS-1,5-4_1x04_P5.00mm_Horizontal
K7: DATV; Relay_SPDT_Finder_32.21-x000
K8: GPSDXO; Relay_SPDT_Finder_32.21-x000
K9: Fan; Relay_SPDT_Finder_32.21-x000
K10: FINDER-40.52; Relay_DPDT_Finder_40.52
Q2, Q6, Q7, Q8: BC557; TO-92_HandSolder
R1: 0.2 ohm-5W; R_Axial_Power_L20.0mm_W6.4mm_P25.40mm
R12, R25, R26, R27: 10k; R_Axial_DIN0207_L6.3mm_D2.5mm_P10.16mm_Horizontal
R13, R30, R32, R34, R36, R38: 20k; R_Axial_DIN0207_L6.3mm_D2.5mm_P10.16mm_Horizontal
R20, R22, R23, R24: 220; R_Axial_DIN0207_L6.3mm_D2.5mm_P10.16mm_Horizontal
R28, R29, R31, R33, R35: 120k; R_Axial_DIN0207_L6.3mm_D2.5mm_P10.16mm_Horizontal
R37: 40k; R_Axial_DIN0207_L6.3mm_D2.5mm_P10.16mm_Horizontal
U2: DS18B20; TO-92_Inline
U4: L7805; TO-220-3_Vertical
U5, U10, U11, U12: PC817; DIP-4_W7.62mm
U6: L7818; TO-220-3_Vertical

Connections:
/ESP32-S3-DevBoard/5Vmain: C12.1, C13.1, J8.2, K10.14, U4.3 (OUT)
/ESP32-S3-DevBoard/12VPlutoOn: J2.1, J13.2, J21.4, K7.12, K9.11, K10.21, Q6.3 (C), Q7.3 (C), Q8.3 (C), R25.1, R26.1, R27.1, U2.3 (V_{DD})
/ESP32-S3-DevBoard/12Vmain: C10.1, C11.1, D2.1 (K), K10.24, Q2.3 (C), R12.1, R28.1, U4.1 (IN)
/ESP32-S3-DevBoard/18Vmain: C17.1, C18.1, K7.14, U6.3 (OUT)
/ESP32-S3-DevBoard/28Vmain: C16.1, J2.4, J3.2, R29.1, U6.1 (IN)
/ESP32-S3-DevBoard/Apow-IO03: J3.1, R1.2, R37.1
GND: C6.1, C7.1, C8.1, C9.1, C10.2, C11.2, C12.2, C13.2, C14.1, C15.1, C16.2, C17.2, C18.2, D7.2 (A), D12.2 (A), D13.2 (A), D14.2 (A), D15.2 (A), D16.2 (A), D17.2 (A), D18.2 (A), D19.2 (A), D20.2 (A), J1.2, J2.2, J2.3, J8.1, J9.1, J9.21, J9.22, J10.1, J11.1, J12.1, J13.1, J18.1, J21.1, K7.A2, K8.A2, K9.A2, K10.A2, R1.1, R13.1, R30.1, R32.1, R34.1, R36.1, R38.1, U2.1 (GND), U4.2 (GND), U5.2, U5.3, U6.2 (GND), U10.2, U10.3, U11.2, U11.3, U12.2, U12.3
unnamed: D2.2 (A), F2.1
unnamed: C6.2, D7.1 (K), J8.19, R13.2, R28.2
unnamed: D12.1 (K), K10.A1, Q2.1 (E)
unnamed: D13.1 (K), K7.A1, Q6.1 (E)
unnamed: D14.1 (K), K8.A1, Q7.1 (E)
unnamed: D15.1 (K), K9.A1, Q8.1 (E)
unnamed: C7.2, D16.1 (K), J8.18, R29.2, R30.2
unnamed: C8.2, D17.1 (K), J8.17, R31.2, R32.2
unnamed: C9.2, D18.1 (K), J8.16, R33.2, R34.2
unnamed: C14.2, D19.1 (K), J8.11, R35.2, R36.2
unnamed: C15.2, D20.1 (K), J8.10, R37.2, R38.2
unnamed: J8.6, J22.4
unnamed: J8.5, J22.3
unnamed: J8.4, J22.2
unnamed: J8.3, J22.1
unnamed: J9.11, R20.1
unnamed: J9.10, R24.1
unnamed: J9.9, R23.1
unnamed: J9.8, R22.1
unnamed: J9.15, U2.2 (DQ)
unnamed: J9.16, J21.2, J21.3
unnamed: F2.2, J1.1
unnamed: J10.2, K8.11, K10.11
unnamed: J11.2, K8.14
unnamed: J12.2, K7.11
unnamed: J18.2, K9.14
unnamed: J20.1, R31.1
unnamed: J20.2, R33.1
unnamed: J20.3, R35.1
unnamed: Q2.2 (B), R12.2, U5.4
unnamed: Q6.2 (B), R25.2, U10.4
unnamed: Q7.2 (B), R26.2, U11.4
unnamed: Q8.2 (B), R27.2, U12.4
unnamed: R20.2, U12.1
unnamed: R22.2, U5.1
unnamed: R23.2, U10.1
unnamed: R24.2, U11.1

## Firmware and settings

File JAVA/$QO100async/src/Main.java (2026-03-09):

/* 
 * PROGRAMMA PRINCIPALE DI GESTIONE DELLA CONNESSIONE A
 * ESP32-S3 PER IL CONTROLLO DI ALCUNE FUNZIONI (ACCESO/SPENTO, DATV, FAN ECC.)
 * E PER LA VERIFICA DEI PARAMETRI DEL RTX:
 * 	Vin = tensione ingresso
 * 	Vpower = tensione stadio finale
 * 	Apower = corrente stadio finale
 * 	Win = potenza in ingresso
 * 	Wout = potenza in uscita
 * 	Wref = potenza riflessa
 * 	Tair = temperatura aria in entrata ventilatore
 * 	Uair = umidità cs
 * 	Tpower = tewmperatura nei pressi del dissipatore del finale
 * 
 * 
 * VERSIONE 0  = utilizza solo la conversione PPM, non equalizzatori
 * 
 * Prossimi sviluppi:
 *  Aggiungere altri interruttori
 * 	Inserire equalizzatori per risposta ADC oghni 10% della curva
 * 	Aggiungere parametri di configurazione ora fissi da programma;
 * 		Tempo aggiornamento (ora 2 secondi da impostare su ESP32)
 * 		Colori verde-giallo-rosso dei:
 * 			SWR (verde 1.5 - giallo 2)
 * 			Tair (ve
 * 			Uair
 * 			Tpower
 * 		
 * 
 */

import java.awt.Color;
import java.awt.EventQueue;
import java.awt.Font;
import java.awt.Image;
import java.awt.event.ActionEvent;
import java.awt.event.ActionListener;
import javax.swing.ImageIcon;
import javax.swing.JButton;
import javax.swing.JFrame;
import javax.swing.JTextArea;
import javax.swing.JTextField;
import javax.swing.SwingConstants;
import javax.swing.SwingUtilities;
import javax.swing.Timer;

public class Main {

	/**
	 * 
	 */
	//IP address della ESP32 di default
	public static String IPAddress = "192.168.0.214"; 

	// stato degli interruttori
	public static boolean onOff = false;
	public static boolean datv = false;
	public static boolean gpsdo = false;
	public static boolean fan = false;
	public static boolean open5 = false;
	public static boolean open6 = false;
	// se ne possono aggiungere altri
	
	
	// tensioni misurate convertite in digitale (0-4095)
	public static int Vin =0;
	public static int Vpower=0;
	public static int Apower =0;
	public static int mWin =0;
	public static int Wout =0;
	public static int Wref =0;
	public static int SWR =0;
	public static int Tair =0;
	public static int Uair =0;
	public static int Tpower =0;
	
	// to test if values have changed
	public static int checkChange =0; 
	public static int prevCheckChange = 0;

	//elementi del main frame
	private JFrame frame;
	private JTextField txtVin;
	private JTextField txtVpower;
	private JTextField txtAPower;
	private JTextField txtMwIn;
	private JTextField txtWOut;
	private JTextField txtWRef;
	private JTextField txtSwr;
	private JTextField txtTAir;
	private JTextField txtUAir;
	private JTextField txtPower;
	private static JTextField resVin;
	private static JTextField resVpower;
	private static JTextField resApower;
	private static JTextField resmWin;
	private static JTextField resWout;
	private static JTextField resWref;
	private static JTextField resSwr;
	private static JTextField resTair;
	private static JTextField resUair;
	private static JTextField resTpower;
	private JTextField txtIP;
	private JTextField textIP;
	
	private static JButton btnOnOff;
	private static JButton btnDatv;
	private static JButton btnGpsdo;
	private static JButton btnFan;
	private static JButton btnOpen5;
	private static JButton btnOpen6;
	
	// oggetto che servirà per vedere se il frame di configurazione è già attivo per non attivarne un secondo.
	private Configuration secondFrame;
	
	// dati di configurazione salvati su file "C:/Users/Andrea.DESKTOP-IK5K4JJ/AppData/Roaming/QO-100async/config.json/"
	public static Config config;
	private static JTextField textChanged;

	/**
	 * Launch the application.
	 */
	public static void main(String[] args) {
		EventQueue.invokeLater(new Runnable() {
			public void run() {
				try {
					Main window = new Main();
					window.frame.setVisible(true);
				} catch (Exception e) {
					e.printStackTrace();
				}
			}
		});
	    
		// leggi la configurazione da JSON
		config = Configuration.leggiConfig();
		// show IP address connected (useless)
		IPAddress = config.IPAddress;
	
		// start Websocket
		new Esp32WS();
        Esp32WS.main(null);
    
	}


	/**
	 * Create the application.
	 */
	public Main() {
		// start initializing all objects of the frame

		initialize();

	}

	// to call the routine that changes all the values after the last read in an asynchronous way (.invokelater)
    public static void updateValues() {
        SwingUtilities.invokeLater(() ->
        updateScreen()
        );
    }
    
    // to round the numbers ( for example 2 digits temp = 10^2 = 100 so the number is multiplied by 100 and later divided.
    public static double arrotonda(double value, int digit) {
        double temp = Math.pow(10, digit);
        return Math.round(value * temp) / temp;
     }
    
    // update all measures read
    public static void updateScreen() {
    	
    	
    	// check if any number is changed. If yes blink.
    	// if not blinking for long time means that dat are not flowing in.
    	prevCheckChange = checkChange;
    	
    	// checkChange, it will change everytime a new reading is performed. Very impossible it is always the same
    	checkChange = Vin+Vpower+Apower+mWin+Wout+Wref+Tair+Uair+Tpower;
    	
    	if (prevCheckChange != checkChange) {
    		textChanged.setBackground(Color.green);
    		int delayTime = 300; // 0,3 secondi
    		new Timer(delayTime, new ActionListener() {
    	  	public void actionPerformed(ActionEvent e) {
    	     		textChanged.setBackground(Color.white);
    	     		// stop the timer
    	     		((Timer) e.getSource()).stop();
    	  	}
    		}).start();
    	};
    	
    	
    	// update relays
       	if (onOff) {
            btnOnOff.setBackground(Color.green);
        } else {
            btnOnOff.setBackground(Color.white);
        }
        
    	if (datv) {
            btnDatv.setBackground(Color.green);
        } else {
            btnDatv.setBackground(Color.white);
        }
    	
    	
    	if (gpsdo) {
            btnGpsdo.setBackground(Color.green);
        } else {
            btnGpsdo.setBackground(Color.white);
        }
        if (fan) {
            btnFan.setBackground(Color.green);
        } else {
            btnFan.setBackground(Color.white);
        }
    
        if (open5) {
            btnOpen5.setBackground(Color.green);
        } else {
            btnOpen5.setBackground(Color.white);
        }
        
        if (open6) {
            btnOpen6.setBackground(Color.green);
        } else {
            btnOpen6.setBackground(Color.white);
        }
    	

    	// update measures afte calculations
    	// Calcolo in base ai PPM
    	double p1 = arrotonda(Vin / config.PIN1_PPM,2);
    	double p2 = arrotonda(Vpower / config.PIN2_PPM,2);
    	double p3 = arrotonda(Apower/ config.PIN3_PPM,2);
    	double p4 = arrotonda(mWin / config.PIN4_PPM,2);
    	double p5 = arrotonda(Wout/ config.PIN5_PPM,2);
    	double p6 = arrotonda(Wref/ config.PIN6_PPM,2);
    	double swr = arrotonda((1+p6/p5)/(1-p6/p5),2);
    	double p11 = arrotonda(Tair,0);
    	double p12 = arrotonda(Uair,0);
    	double p13 = arrotonda(Tpower,0);
    	
    	 resVin.setText(Double.toString(p1));
    	 resVpower.setText(Double.toString(p2));
    	 resApower.setText(Double.toString(p3));
    	 resmWin.setText(Double.toString(p4));
    	 resWout.setText(Double.toString(p5));
    	 resWref.setText(Double.toString(p6));
    	 resSwr.setText(Double.toString(swr));	 
    	 resTair.setText(Double.toString(p11));
    	 resUair.setText(Double.toString(p12));
    	 resTpower.setText(Double.toString(p13));
    	 

    	
    	 // calcolo dei colori
    	 int green = (int) (4095 * config.PIN1_GREEN);
    	 int yellow = (int) (4095 * config.PIN1_YELLOW);
    	 
    	 System.out.println("Vin="+Vin+"   p1="+p1+"   green="+green+"    yellow="+yellow);
    	 // double red = 4095 * config.PIN1_RED;
    	 if (green != 0) {			 //se config.PINx_GREEN = 0 non vengono gestiti i colori
    		 if (Vin <= green) {
    			 // campo verde
    			 resVin.setBackground(Color.green);
    		 } else {
    			 if ((Vin > green) && (Vin <= yellow)) {
    				// campo giallo
    				 resVin.setBackground(Color.yellow);
    			 } else {
    				// campo rosso
    				 resVin.setBackground(Color.red);
    			 }	 
    		 }
    	 }
    	 
    	green = (int) (4095 *4095 * config.PIN2_GREEN); 
    	yellow = (int) (4095 *4095 * config.PIN2_YELLOW);
    	 // double red = 4095 * config.PIN1_RED;
    	 if (green != 0) {			 //se config.PINx_GREEN = 0 non vengono gestiti i colori
    		 if (Vpower <= green) {
    			 // campo verde
    			 resVpower.setBackground(Color.green);
    		 } else {
    			 if (Vpower > green && Vpower < yellow) {
    				// campo giallo
    				 resVpower.setBackground(Color.yellow);
    			 } else {
    				// campo rosso
    				 resVpower.setBackground(Color.red);
    			 }	 
    		 }
    	 }
    	 
     	green = (int) (4095 *4095 * config.PIN3_GREEN);  
     	yellow = (int) (4095 *4095 * config.PIN3_YELLOW); 
     	 // double red = 4095 * config.PIN1_RED;
      	 if (green != 0) {			 //se config.PINx_GREEN = 0 non vengono gestiti i colori
    		 if (Apower <= green) {
    			 // campo verde
    			 resApower.setBackground(Color.green);
    		 } else {
    			 if (Apower > green && Apower < yellow) {
    				// campo giallo
    				 resVpower.setBackground(Color.yellow);
    			 } else {
    				// campo rosso
    				 resApower.setBackground(Color.red);
    			 }	 
    		 }
    	 }
    	 
     	green = (int) (4095 *4095 * config.PIN4_GREEN); 
     	yellow = (int) (4095 *4095 * config.PIN4_YELLOW); 
     	 // double red = 4095 * config.PIN1_RED;
     	 if (green != 0) {			 //se config.PINx_GREEN = 0 non vengono gestiti i colori
     		 if (p1 <= green) {
     			 // campo verde
     			 resmWin.setBackground(Color.green);
     		 } else {
     			 if (mWin > green && mWin < yellow) {
     				// campo giallo
     				 resmWin.setBackground(Color.yellow);
     			 } else {
     				// campo rosso
     				 resmWin.setBackground(Color.red);
     			 }	 
     		 }
     	 }
     	 
     	green = (int) (4095 *4095 * config.PIN5_GREEN); 
     	yellow = (int) (4095 *4095 * config.PIN5_YELLOW); 
     	 // double red = 4095 * config.PIN1_RED;
   	 if (green != 0) {			 //se config.PINx_GREEN = 0 non vengono gestiti i colori
		 if (Wout <= green) {
			 // campo verde
			 resWout.setBackground(Color.green);
		 } else {
			 if ((Wout > green) && (Wout <= yellow)) {
				// campo giallo
				 resWout.setBackground(Color.yellow);
			 } else {
				// campo rosso
				 resWout.setBackground(Color.red);
			 }	 
		 }
	 }
     	 
     	green = (int) (4095 *4095 * config.PIN6_GREEN); 
     	yellow = (int) (4095 *4095 * config.PIN6_YELLOW);
     	 // double red = 4095 * config.PIN1_RED;
   	 if (green != 0) {			 //se config.PINx_GREEN = 0 non vengono gestiti i colori
		 if (Wref <= green) {
			 // campo verde
			 resWref.setBackground(Color.green);
		 } else {
			 if ((Wref > green) && (Wref <= yellow)) {
				// campo giallo
				 resWref.setBackground(Color.yellow);
			 } else {
				// campo rosso
				 resWref.setBackground(Color.red);
			 }	 
		 }
	 }
     	 
  	 //SWR è fisso da programma
		 if (swr <= 1.5) {
			 // campo verde
			 resSwr.setBackground(Color.green);
		 } else {
			 if ((swr > 1.5) && (swr <= 2)) {
				// campo giallo
				 resSwr.setBackground(Color.yellow);
			 } else {
				// campo rosso
				 resSwr.setBackground(Color.red);
			 }	 
		 }
		 
	  	 //Tair è fisso da programma
			 if (Tair <= 28.0) {
				 // campo verde
				 resTair.setBackground(Color.green);
			 } else {
				 if ((Tair > 28.0) && (Tair <= 35.0)) {
					// campo giallo
					 resTair.setBackground(Color.yellow);
				 } else {
					// campo rosso
					 resTair.setBackground(Color.red);
				 }	 
			 }
			 
		  	 //Uair è fisso da programma
			 if (Uair <= 60.0) {
				 // campo verde
				 resUair.setBackground(Color.green);
			 } else {
				 if ((Uair > 60.0) && (Uair <= 80.0)) {
					// campo giallo
					 resUair.setBackground(Color.yellow);
				 } else {
					// campo rosso
					 resUair.setBackground(Color.red);
				 }	 
			 }

		  	 //Tpower è fisso da programma
			 if (Tpower <= 40.0) {
				 // campo verde
				 resTpower.setBackground(Color.green);
			 } else {
				 if ((Tpower > 40.0) && (Tpower <= 55.0)) {
					// campo giallo
					 resTpower.setBackground(Color.yellow);
				 } else {
					// campo rosso
					 resTpower.setBackground(Color.red);
				 }	 
			 }
			 
			 if (onOff ) {
				 // campo verde
				//btnOnOff.setBackgroud(Color.green);
			 } else {}	 
			 
    	 
    }
    
    
    // update the switches (relays) as soon as the json is read
    public static void updateRelays() {

        SwingUtilities.invokeLater(() -> {

        	if (onOff) {
                btnOnOff.setBackground(Color.green);
            } else {
                btnOnOff.setBackground(Color.white);
            }
            
        	if (datv) {
                btnDatv.setBackground(Color.green);
            } else {
                btnDatv.setBackground(Color.white);
            }
        	
        	
        	if (gpsdo) {
                btnGpsdo.setBackground(Color.green);
            } else {
                btnGpsdo.setBackground(Color.white);
            }
            if (fan) {
                btnFan.setBackground(Color.green);
            } else {
                btnFan.setBackground(Color.white);
            }
        
            if (open5) {
                btnOpen5.setBackground(Color.green);
            } else {
                btnOpen5.setBackground(Color.white);
            }
            
            if (open6) {
                btnOpen6.setBackground(Color.green);
            } else {
                btnOpen6.setBackground(Color.white);
            }
            

        });
    }
	/**
	 * Initialize the contents of the frame.
	 */

    private void initialize() {
		
		frame = new JFrame();
		Image img = new ImageIcon(this.getClass().getResource("/Parabola.png")).getImage();
		frame.setIconImage(img);
		frame.setBounds(100, 100, 652, 158);
		frame.setDefaultCloseOperation(JFrame.EXIT_ON_CLOSE);
		frame.getContentPane().setLayout(null);
		//frame.setIconImage(logo.getImage());
		
		btnOnOff = new JButton("On/Off");
		btnOnOff.addActionListener(new ActionListener() {
			public void actionPerformed(ActionEvent e) {
				 if (onOff ) {
					 // campo verde
					btnOnOff.setBackground(Color.white);
					Esp32Post.send("{\"onOff\": false}");
				 } else {
						btnOnOff.setBackground(Color.green);
						Esp32Post.send("{\"onOff\": true}");
				 }	

			}
		});
		btnOnOff.setBounds(115, 25, 71, 23);
		frame.getContentPane().add(btnOnOff);
		

		btnDatv = new JButton("DATV");
		btnDatv.addActionListener(new ActionListener() {
			public void actionPerformed(ActionEvent e) {

				 if (datv) {
					 // campo verde
					btnDatv.setBackground(Color.white);
					Esp32Post.send("{\"datv\": false}");
				 } else {
						btnDatv.setBackground(Color.green);
						Esp32Post.send("{\"datv\": true}");
				 }	
			}
		});
		btnDatv.setBounds(196, 25, 71, 23);
		frame.getContentPane().add(btnDatv);

		btnGpsdo = new JButton("GPSDO");
		if(gpsdo) {btnGpsdo.setBackground(Color.green);		}
		btnGpsdo.addActionListener(new ActionListener() {
			public void actionPerformed(ActionEvent e) {
				 if (gpsdo) {
					 // campo verde
					btnGpsdo.setBackground(Color.white);
					Esp32Post.send("{\"gpsdo\":false}");
				 } else {
						btnGpsdo.setBackground(Color.green);
						Esp32Post.send("{\"gpsdo\":true}");
				 }		
				
			}
		});
		btnGpsdo.setBounds(277, 25, 71, 23);
		frame.getContentPane().add(btnGpsdo);
	

		btnFan = new JButton("FAN");
		btnFan.addActionListener(new ActionListener() {
			public void actionPerformed(ActionEvent e) {
				 if (fan) {
					 // campo verde
					btnFan.setBackground(Color.white);
					Esp32Post.send("{\"fan\":false}");
				 } else {
						btnFan.setBackground(Color.green);
						Esp32Post.send("{\"fan\":true}");
				 }		
			}
		});
		btnFan.setBounds(362, 25, 71, 23);
		frame.getContentPane().add(btnFan);
		
		btnOpen5 = new JButton(".....1");
		btnOpen5.addActionListener(new ActionListener() {
			public void actionPerformed(ActionEvent e) {
				 if (open5) {
					 // campo verde
					btnOpen5.setBackground(Color.white);
					Esp32Post.send("{\"open5\":false}");
				 } else {
						btnOpen5.setBackground(Color.green);
						Esp32Post.send("{\"open5\":true}");
				 }					
			}
		});	
		btnOpen5.setBounds(443, 25, 71, 23);
		frame.getContentPane().add(btnOpen5);

		btnOpen6 = new JButton(".....2");
		btnOpen6.addActionListener(new ActionListener() {
			public void actionPerformed(ActionEvent e) {
				 if (open6) {
					 // campo verde
					btnOpen6.setBackground(Color.white);
					Esp32Post.send("{\"open6\":false}");
				 } else {
						btnOpen6.setBackground(Color.green);
						Esp32Post.send("{\"open6\":true}");
				 }			
				
			}
		});
		btnOpen6.setBounds(521, 25, 71, 23);
		frame.getContentPane().add(btnOpen6);
		
		
		
		JTextArea txtrQoRtxController = new JTextArea();
		txtrQoRtxController.setWrapStyleWord(true);
		txtrQoRtxController.setFont(new Font("Arial Black", Font.PLAIN, 12));
		txtrQoRtxController.setText("QO-100 RTX\r\nController");
		txtrQoRtxController.setBounds(10, 0, 90, 48);
		frame.getContentPane().add(txtrQoRtxController);
		
		
		txtVin = new JTextField();
		txtVin.setText("Vin");
		txtVin.setHorizontalAlignment(SwingConstants.CENTER);
		txtVin.setColumns(10);
		txtVin.setBounds(10, 59, 52, 23);
		frame.getContentPane().add(txtVin);
		
		txtVpower = new JTextField();
		txtVpower.setText("V power");
		txtVpower.setHorizontalAlignment(SwingConstants.CENTER);
		txtVpower.setColumns(10);
		txtVpower.setBounds(72, 59, 52, 23);
		frame.getContentPane().add(txtVpower);
		
		txtAPower = new JTextField();
		txtAPower.setText("A power");
		txtAPower.setHorizontalAlignment(SwingConstants.CENTER);
		txtAPower.setColumns(10);
		txtAPower.setBounds(134, 59, 52, 23);
		frame.getContentPane().add(txtAPower);
		
		txtMwIn = new JTextField();
		txtMwIn.setText("mW in");
		txtMwIn.setHorizontalAlignment(SwingConstants.CENTER);
		txtMwIn.setColumns(10);
		txtMwIn.setBounds(196, 59, 52, 23);
		frame.getContentPane().add(txtMwIn);
		
		txtWOut = new JTextField();
		txtWOut.setText("W out");
		txtWOut.setHorizontalAlignment(SwingConstants.CENTER);
		txtWOut.setColumns(10);
		txtWOut.setBounds(257, 59, 52, 23);
		frame.getContentPane().add(txtWOut);
		
		txtWRef = new JTextField();
		txtWRef.setText("W ref");
		txtWRef.setHorizontalAlignment(SwingConstants.CENTER);
		txtWRef.setColumns(10);
		txtWRef.setBounds(319, 59, 52, 23);
		frame.getContentPane().add(txtWRef);
		
		txtSwr = new JTextField();
		txtSwr.setText("SWR");
		txtSwr.setHorizontalAlignment(SwingConstants.CENTER);
		txtSwr.setColumns(10);
		txtSwr.setBounds(381, 59, 52, 23);
		frame.getContentPane().add(txtSwr);
		
		txtTAir = new JTextField();
		txtTAir.setText("T air");
		txtTAir.setHorizontalAlignment(SwingConstants.CENTER);
		txtTAir.setColumns(10);
		txtTAir.setBounds(443, 59, 52, 23);
		frame.getContentPane().add(txtTAir);
		
		txtUAir = new JTextField();
		txtUAir.setText("U% air");
		txtUAir.setHorizontalAlignment(SwingConstants.CENTER);
		txtUAir.setColumns(10);
		txtUAir.setBounds(503, 59, 52, 23);
		frame.getContentPane().add(txtUAir);
		
		txtPower = new JTextField();
		txtPower.setText("T power");
		txtPower.setHorizontalAlignment(SwingConstants.CENTER);
		txtPower.setColumns(10);
		txtPower.setBounds(565, 59, 52, 23);
		frame.getContentPane().add(txtPower);
		
		resVin = new JTextField();
		resVin.setText("0");
		resVin.setHorizontalAlignment(SwingConstants.CENTER);
		resVin.setColumns(10);
		resVin.setBounds(10, 88, 52, 23);
		frame.getContentPane().add(resVin);
		
		resVpower = new JTextField();
		resVpower.setText("0");
		resVpower.setHorizontalAlignment(SwingConstants.CENTER);
		resVpower.setColumns(10);
		resVpower.setBounds(72, 88, 52, 23);
		frame.getContentPane().add(resVpower);
		
		resApower = new JTextField();
		resApower.setText("0");
		resApower.setHorizontalAlignment(SwingConstants.CENTER);
		resApower.setColumns(10);
		resApower.setBounds(134, 88, 52, 23);
		frame.getContentPane().add(resApower);
		
		resmWin = new JTextField();
		resmWin.setText("0");
		resmWin.setHorizontalAlignment(SwingConstants.CENTER);
		resmWin.setColumns(10);
		resmWin.setBounds(196, 88, 52, 23);
		frame.getContentPane().add(resmWin);
		
		resWout = new JTextField();
		resWout.setText("0");
		resWout.setHorizontalAlignment(SwingConstants.CENTER);
		resWout.setColumns(10);
		resWout.setBounds(257, 88, 52, 23);
		frame.getContentPane().add(resWout);
		
		resWref = new JTextField();
		resWref.setText("0");
		resWref.setHorizontalAlignment(SwingConstants.CENTER);
		resWref.setColumns(10);
		resWref.setBounds(319, 88, 52, 23);
		frame.getContentPane().add(resWref);
		
		resSwr = new JTextField();
		resSwr.setText("0");
		resSwr.setHorizontalAlignment(SwingConstants.CENTER);
		resSwr.setColumns(10);
		resSwr.setBounds(381, 88, 52, 23);
		frame.getContentPane().add(resSwr);
		
		resTair = new JTextField();
		resTair.setText("0");
		resTair.setHorizontalAlignment(SwingConstants.CENTER);
		resTair.setColumns(10);
		resTair.setBounds(443, 88, 52, 23);
		frame.getContentPane().add(resTair);
		
		resUair = new JTextField();
		resUair.setText("0");
		resUair.setHorizontalAlignment(SwingConstants.CENTER);
		resUair.setColumns(10);
		resUair.setBounds(503, 88, 52, 23);
		frame.getContentPane().add(resUair);
		
		resTpower = new JTextField();
		resTpower.setText("0");
		resTpower.setHorizontalAlignment(SwingConstants.CENTER);
		resTpower.setColumns(10);
		resTpower.setBounds(565, 88, 52, 23);
		frame.getContentPane().add(resTpower);

		
		// pulsante settings : se s2 esiste non viene attivata una nuova finestra ndi configurazione
		JButton btnSetting = new JButton("...");
		
		 btnSetting.addActionListener(e -> {
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

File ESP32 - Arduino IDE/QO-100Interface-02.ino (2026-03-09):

// versione 01

#include <WiFi.h>
#include <AsyncTCP.h>
#include <ESPAsyncWebServer.h>
#include <ArduinoJson.h>

// for DHT22
#include <DHT.h>

// for DS18B20
#include <OneWire.h>
#include <DallasTemperature.h>

// update of the parameters in milliseconds
const int cycleTime = 1000;  // in millisecondi

// enter wifi parameters ( to be improved)
const char* ssid = "SKYAP2";
const char* password = "aaabbbcccddd";

// create the async server on port 80
AsyncWebServer server(80);
AsyncWebSocket ws("/ws");

// ===== PIN =====

const int Vin = 1;
const int Vpower = 2;
const int Apower = 3;
const int Win = 4;
const int Wout = 5;
const int Wref = 6;

const int ONOFF = 7;
const int DATV = 8;
const int GPSDO = 9;

const int DHT1_PIN = 10;
const int DS18B20 = 11;
const int FAN = 12;
const int OPEN5 = 13;
const int OPEN6 = 14;



// DHT22 temperature and umidity (air) definition
#define DHTTYPE DHT22
DHT dht1(DHT1_PIN, DHTTYPE);

//DS18B20 temperature probe (P.A.) definition
#define ONE_WIRE_BUS DS18B20
OneWire oneWire(ONE_WIRE_BUS);
DallasTemperature sensors(&oneWire);



// ===== STATO =====
StaticJsonDocument<512> stato;

// ===== UPDATE HARDWARE =====
void aggiornaRelay() {
  digitalWrite(ONOFF, stato["onOff"] ? HIGH : LOW);
  digitalWrite(DATV, stato["datv"] ? HIGH : LOW);
  digitalWrite(GPSDO, stato["gpsdo"] ? HIGH : LOW);
  digitalWrite(FAN, stato["fan"] ? HIGH : LOW);
  digitalWrite(OPEN5, stato["open5"] ? HIGH : LOW);
  digitalWrite(OPEN6, stato["open6"] ? HIGH : LOW);

  // ad other digital controls
}

// read all input
void aggiornaIngressi() {

  stato["Vin"] = analogRead(Vin);
  stato["Vpower"] = analogRead(Vpower);
  stato["Apower"] = analogRead(Apower);
  stato["Win"] = analogRead(Win); 
  stato["Wout"] = analogRead(Wout);
  stato["Wref"] = analogRead(Wref);

  sensors.requestTemperatures();
  float tempPA = sensors.getTempCByIndex(0);

  float t1 = dht1.readTemperature();
  float h1 = dht1.readHumidity();
 

  if (!isnan(t1) && !isnan(h1)) {
    //stato["dht10"]["t"] = t1;
    //stato["dht10"]["h"] = h1;
    stato["Tair"] = t1;
    stato["Uair"] = h1;

  }
  if (!isnan(tempPA) ) {
     stato["Tpower"] = tempPA;
 }
}

// ===== PUSH STATO =====
// send data read to JSON
void broadcastStato() {
  String json;
  serializeJson(stato, json);
  ws.textAll(json);
  Serial.println(json);
}

// ===== WS EVENTS =====
// everytime a new valid event is detected write it into JSON 
void onWsEvent(AsyncWebSocket *server,
               AsyncWebSocketClient *client,
               AwsEventType type,
               void *arg,
               uint8_t *data,
               size_t len) {

  if (type == WS_EVT_CONNECT) {
    broadcastStato();
  }
}

// ===== INITIAL SETUP =====
void setup() {
  
  // start serial port
  Serial.begin(115200);

    // start reading sensors
  dht1.begin();
  sensors.begin();
  
  // define pi scope
  pinMode(ONOFF, OUTPUT);
  pinMode(DATV, OUTPUT);
  pinMode(GPSDO, OUTPUT);
  pinMode(FAN, OUTPUT);
  pinMode(OPEN5, OUTPUT);
  pinMode(OPEN6, OUTPUT);

  // all off when started and update
  stato["onOff"] = false;
  stato["datv"] = false;
  stato["gpsdo"] = false;
  stato["fan"] = false;
  stato["open5"] = false;
  stato["open6"] = false;


  aggiornaRelay();

  //start wifi with a little delay before proceeding
  WiFi.begin(ssid, password);
  while (WiFi.status() != WL_CONNECTED) delay(500);
  
  Serial.println("");
  Serial.println("WiFi connected");
  Serial.println("IP address: ");
  Serial.println(WiFi.localIP());

  // start Webserver with the defined onWsEvent function and the right soket
  ws.onEvent(onWsEvent);
  server.addHandler(&ws);

  // ===== POST COMANDI =====
  // get the command input, check if JSON is right and decode the json 
  //assigning the comands to the relays
  server.on("/command", HTTP_POST,
    [](AsyncWebServerRequest *request) {},
    NULL,
    [](AsyncWebServerRequest *request,
       uint8_t *data, size_t len,
       size_t index, size_t total) {

      StaticJsonDocument<200> input;
      if (deserializeJson(input, data)) {
        request->send(400, "text/plain", "JSON errato");
        return;
      }

      if (input.containsKey("onOff")) stato["onOff"] = input["onOff"];
      if (input.containsKey("datv")) stato["datv"] = input["datv"];
      if (input.containsKey("gpsdo")) stato["gpsdo"] = input["gpsdo"];
      if (input.containsKey("fan")) stato["fan"] = input["fan"];
      if (input.containsKey("open5")) stato["open5"] = input["open5"];
      if (input.containsKey("open6")) stato["open6"] = input["open6"];


      aggiornaRelay();
      broadcastStato();
      request->send(200, "text/plain", "OK");
    });

  server.begin();
}

// ===== LOOP NON BLOCCANTE =====

// counter for defining the period
unsigned long lastRead = 0;

// continuos look - every cycletime update the system
void loop() {
  if (millis() - lastRead > cycleTime) {   
    lastRead = millis();

    Serial.println(lastRead);
    
    aggiornaIngressi();
    aggiornaRelay();
    broadcastStato();
  }
}

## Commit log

2026-03-09 Create ESP32
2026-09-24 Delete Pluto via Ethernet though Raspberry.pdf
    new ver
